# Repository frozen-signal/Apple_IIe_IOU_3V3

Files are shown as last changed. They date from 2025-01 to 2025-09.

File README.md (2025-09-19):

# Description
This repository contains the reference design for a 3.3V version of the Apple IIe's IOU custom IC.</br>
The RTL (VHDL source code) project is located here: [RTL for the Apple IIe's MMU and IOU](https://github.com/frozen-signal/Apple_IIe_MMU_IOU)

## Project status
<br/>

## Acknowledgements

This project was made possible thanks to the support and contributions of a few key individuals.<br/>
Notable thanks go to:
 * **Henry S. Courbis of ReActiveMicro** not only was instrumental in the development of the VHDL code but also was the spark that initiated this project. His generous support and deep technical insight made this project possible.
 * **[Ralle Palaveev](https://github.com/rallepalaveev)** is more than a contributor -- he is the co-creator of the 3.3V adapters. His impressive skills made what seemed impossible look easy: fitting everything into a 40-pin DIP-sized PCB.

And lastly, a special thanks to **Leeland Heins [@SoftwareJanitor](https://github.com/softwarejanitor)**, who thoroughly tested this project. His steady encouragement was a much-appreciated source of motivation during the tougher stretches of development.

## The IOU Adapter
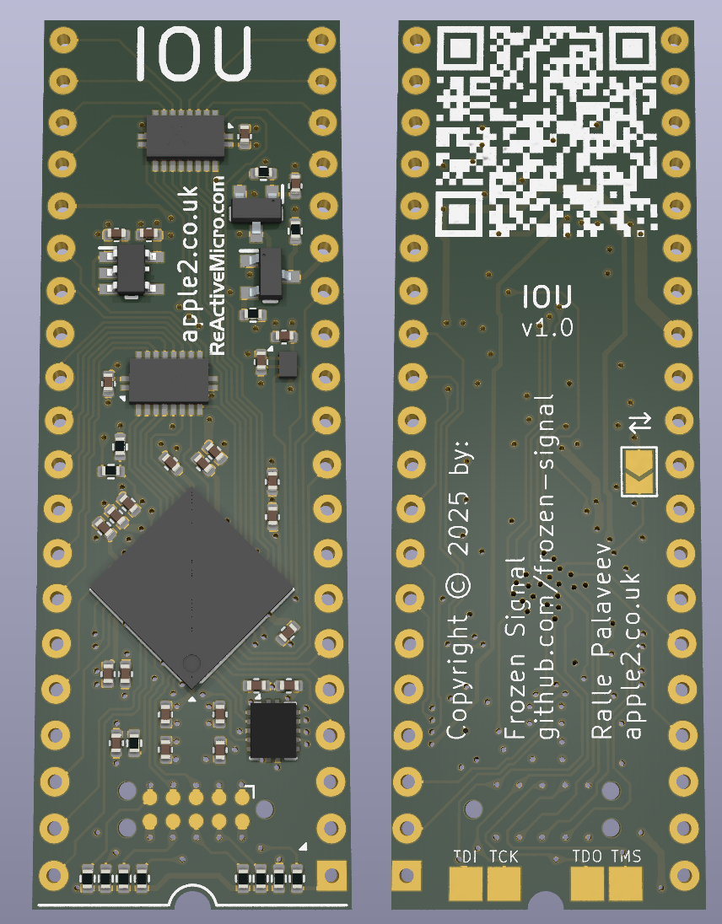
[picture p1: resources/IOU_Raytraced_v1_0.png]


**Buying the IOU Adapter**
<br/>
The two official stores where to buy the IOU adapter are _ReActiveMicro_ and _Ralle Palaveev's store_.<br/>
<br/>
<a href="https://apple2.co.uk/Products">Ralle Palaveev's store</a><br/>
<a href="https://www.reactivemicro.com/">ReActiveMicro</a> (Available soon)<br/>
<br/>

**Building it yourself**
<br/>
Gerbers, production files, and instructions are located in [production](production/)

<br clear="all">

## Tested Hardware

| Category | Hardware Components |
|---|---|
| **Motherboards** | <ul><li>Rev.B motherboard (NTSC)</li><li>ReActiveMicro IIe motherboard (NTSC)</li><li>Pravetz 8E</li><li>Pravetz 8A</li></ul> |
| **CPUs** | <ul><li>Synertek 6502 (unenhanced ROMs)</li><li>Rockwell R6502AP (unenhanced ROMs)</li><li>UMC UM6502 (unenhanced ROMs)</li><li>GTE G65SC02P-2 (enhanced ROMs)</li><li>NCR 65C02 (enhanced ROMs)</li><li>Rockwell R65C02P4 (enhanced ROMs)</li><li>WDC 65C02S (with adapter)</li></ul> |
| **AUX Cards** | <ul><li>RAMWorks III (512M)</li><li>80-Column Expansion Card (820-0067-B)</li><li>80-Column Expansion Card (820-0067-D)</li><li>AE Ramworks ][</li><li>Apple "Slinky" RAM card</li></ul> |
| **ROMs** | <ul><li>Enhanced ROM set (ReActiveMicro)</li><li>Unenhanced ROMs:<ul><li>342-0132-B</li><li>342-0133-A</li><li>342-0134-A</li><li>342-0135-A</li></ul></li></ul> |
| **Disk Interfaces/Drive** | <ul><li>Apple 5.25" Drive Controller Card (655-0101-E)</li><li>Disk ][ Interface Card (650-X104)</li><li>Apple Disk II Drive</li><li>NVRam Drive</li><li>BOMW FloppyEMU</li><li>A2DISK</li><li>Franklin floppy controller</li></ul> |
| **Other** | <ul><li>Mouse Interface Card (670-0030-C)</li><li>Thunderclock Plus</li><li>A2VGA mouse emulation</li><li>Booti</li><li>TJ Boldt's ROM-Drive v4.0</li><li>Grappler+</li><li>A2DVI</li><li>A2Pico</li><li>A2VGA</li><li>Romcard</li><li>Romcard2</li><li>Romcard3</li><li>A2RESET v1,v2</li><li>AE Transwarp</li><li>Titan Accellerator //e</li><li>Ian Kim A2 Turbo</li><li>MS Z80 Softcard clone</li></ul> |

## Other Projects
Other hardware reference designs are located here:
### 3.3V Adapter reference designs
- [3.3V MMU adapter](https://github.com/frozen-signal/Apple_IIe_MMU_3V3)

### 5V Adapter reference designs
- 5V IOU adapter (To be done)
- 5V MMU adapter (To be done)

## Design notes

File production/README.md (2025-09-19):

# Building the IOU Adapter
## DISCLAIMER
This repository is provided "as is". If you choose to fabricate and/or assemble this project yourself, you do so entirely at your own risk. The authors/maintainers provide no warranties (express or implied) and accept no responsibility for any damage, injury, or loss resulting from use or misuse. This design is not certified for safety, EMC, or regulatory compliance; you are solely responsible for verifying suitability, component orientation/polarity, firmware configuration, or any other aspect. By using any files in this repo, you agree to assume all risks.

## Obtaining the PCB
### Required capabilities
Make sure these requirements are within you PCB fab house capabilities:
- Size: 17.46mm x 51.30mm
- 4-Layers
- Smallest via size (hole/dia): 0.3mm / 0.5mm
- Smallest track width: 0.15mm
### BGA solderpads adjustments
Review and/or adjust the BGA's solderpads so that they are within your fab house's mask registration capability or your reflow process if you will be reflowing the components yourself.
Read Lattice's "[PCB Layout Recommendations for BGA Packages (FPGA-TN-02024-5.6)](https://www.latticesemi.com/view_document?document_id=671)" technical note for further details (See section 3 for the 0.5mm ball pitch, csBGA-132).

## Assembly
Soldering the components yourself is not recommended; the FPGA is a 132-ball csBGA (0.5mm pitch) and is beyond the capabilities of most hobbyists. Using the assembly services of your fab house is recommended.
You can use leadframes for the 40 pins of the device, or use 2.54mm pin headers. If you use pin headers, be sure to use a 40-pin socket between them and the Apple IIe's socket; otherwise, the pin headers will damage the Apple IIe's socket.

## Programming
### Requirements
You will need Lattice Diamond to build the code and flash the device.<br/>
Note: You can skip building the JEDEC file by using the one in the [Latest Official Release](https://github.com/frozen-signal/Apple_IIe_IOU_3V3/releases/tag/1.0)

### Build the code
1. Open the project `firmware\IOU.ldf` in Lattice Diamond.
2. In the file `firmware\CUSTOM\IOU.vhdl`, make sure the constant `NTSC_CONSTANT` (line 18) correspond with the version you want:
   | To build this IOU | Use this value |
   | --- | --- |
   | NTSC | `'1'` |
   | PAL | `'0'` |
3. Synthesize and build the JEDEC file

### Flash the MACHXO2
Note: You will need a compatible JTAG programming device to flash the MACHXO2. In doubt, you can use the programmer found here: [JTAG Programmer](https://github.com/frozen-signal/JTAG-Programmer)
1. Connect the programmer and launch the Lattice Diamond Programmer
2. Load the JEDEC file generated earlier
3. Connect the JTAG to the IOU Adapter
4. Program

## Finished
The adapter is ready to be used. Make sure to insert the adapter with the correct orientation in the Apple IIe.

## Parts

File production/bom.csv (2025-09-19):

Designator | Footprint | Quantity | Value | LCSC Part #
 | 72190c3a-44d7-4d1f-8c19-bd071d7af191 | 1
C1, C2, C25 | 0402 | 3 | 1uF
C10, C11, C13, C14, C16, C17, C18, C20, C21, C23, C24, C3, C4, C5, C6, C8 | 0402 | 16 | 100nF
C12, C15, C19, C22, C7, C9 | 0402 | 6 | 10uF
Q1, Q2 | SOT95P240X120-3N | 2 | BSS138 | C7420339
R1, R10, R11, R14, R3, R5, R6, R7, R8, R9 | 0402 | 10 | 4.7K
R12, R13, R2 | 0402 | 3 | 5.1K
R4 | 0402 | 1 | 1K
U1 | SOT95P280X145-5N | 1 | TLV75733PDBVR
U2 | BGA132C50P14X14_800X800X135 | 1 | LCMXO2-256HC-4MG132C
U3 | TXU0101DRYR | 1 | TXU0101DRYR
U4, U6 | 74LVC245ABQ115 | 2 | 74LVC245ABQ,115
U7 | TXU0204BQAR | 1 | TXU0204BQAR

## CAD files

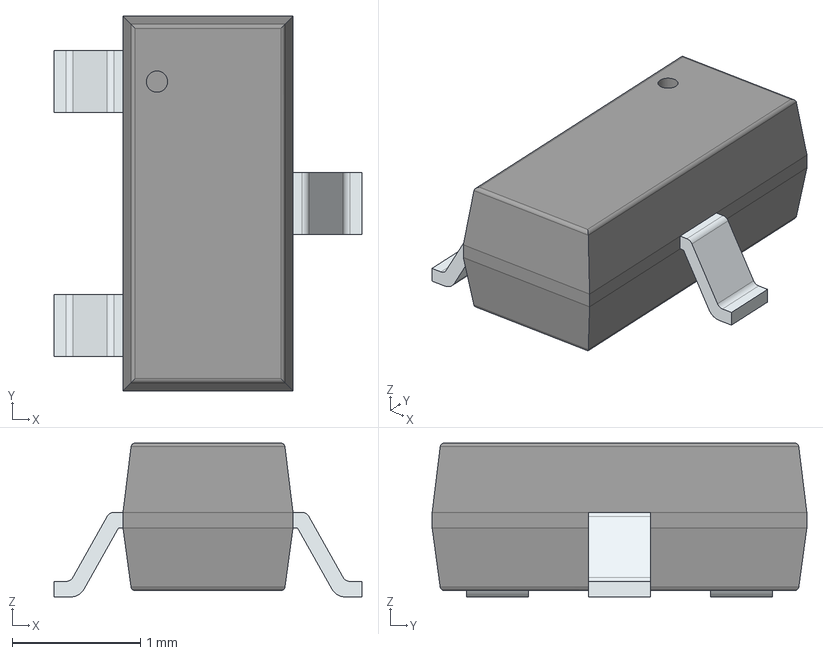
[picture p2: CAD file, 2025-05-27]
3D_Models/BSS138.step
2.40 x 2.92 x 1.20 mm
PinsArrayL
FilletPinR

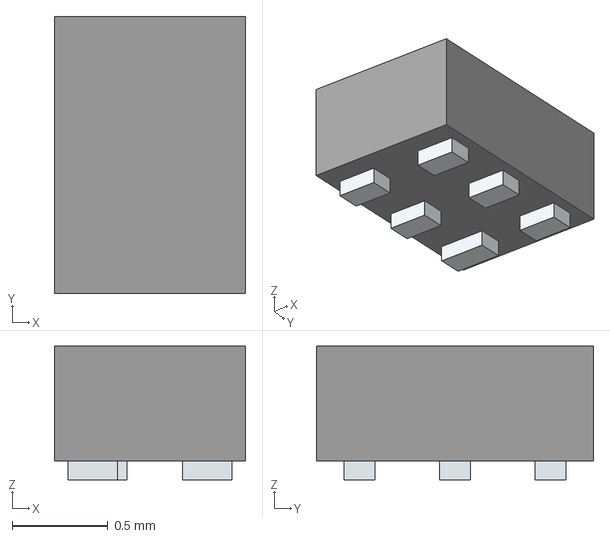
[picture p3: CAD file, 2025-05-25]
3D_Models/TXU0101DRYR.step
1.00 x 1.45 x 0.7 mm
Pins

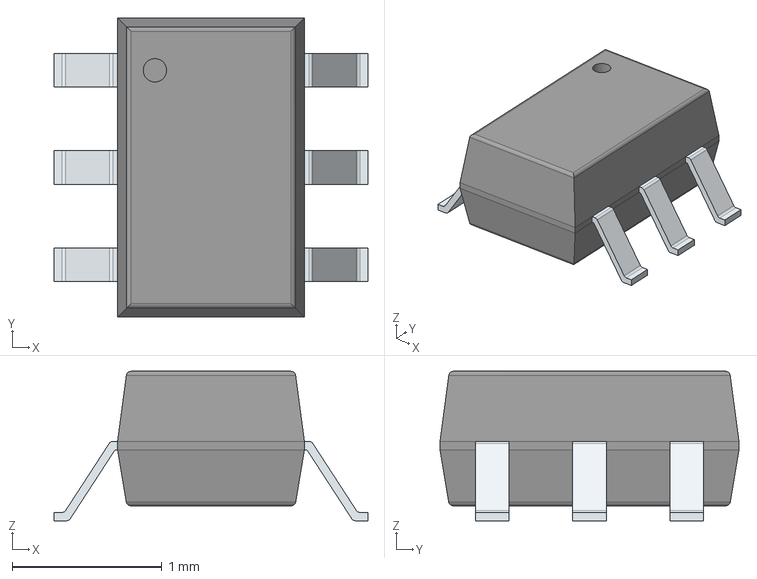
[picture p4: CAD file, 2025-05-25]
3D_Models/BSD235NH6327XTSA1.step
2.10 x 2.00 x 1.00 mm
PinsArrayLR

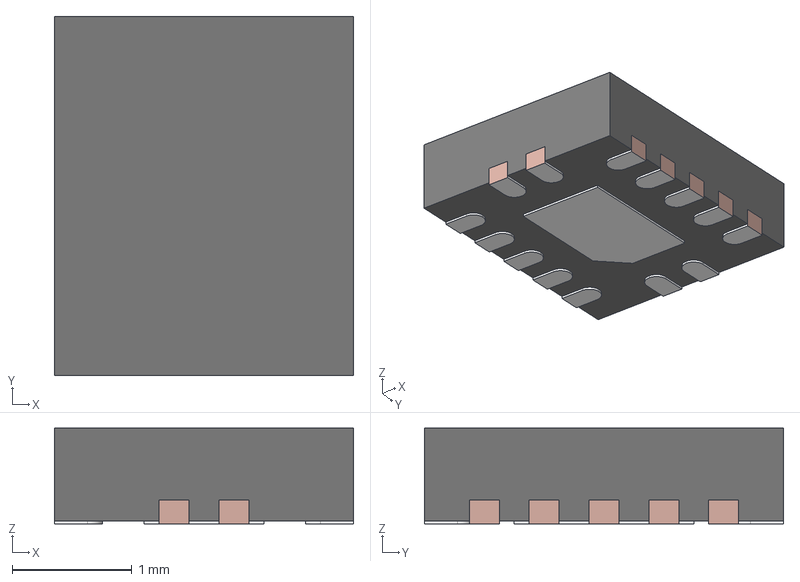
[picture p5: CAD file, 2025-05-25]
3D_Models/TXU0204BQAR.step
2.50 x 3.00 x 0.8 mm
FRAME

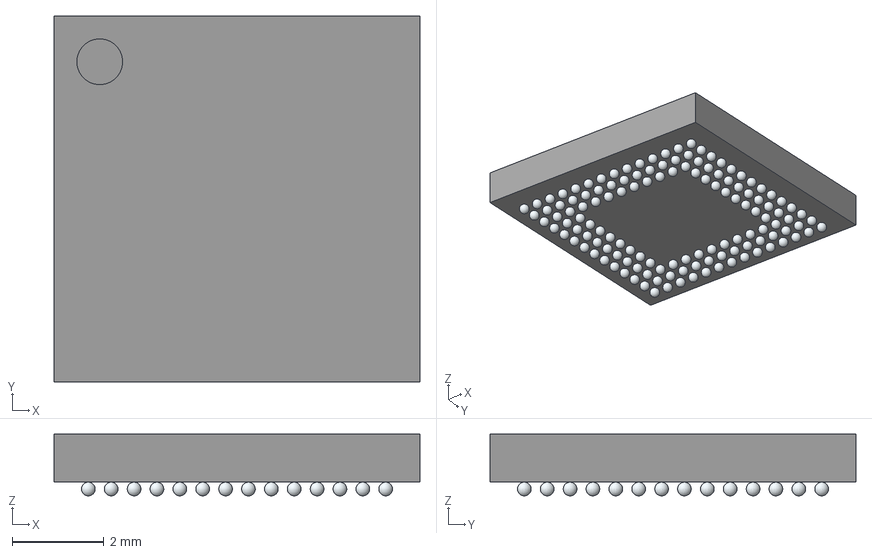
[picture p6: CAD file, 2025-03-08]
3D_Models/LCMXO2-256HC-4MG132C.step
8.00 x 8.00 x 1.35 mm
A1
A2
A3
A4
A5
A6
A7
A8
A9
A10
A11
A12
A13
A14
B1
B2
B3
B4
B5
B6
B7
B8
B9
B10
B11
B12
B13
B14
C1
C2
C3
C4
C5
C6
C7
C8
C9
C10
C11
C12
C13
C14
D1
D2
D3
D12
D13
D14
E1
E2
E3
E12
E13
E14
F1
F2
F3
F12
F13
F14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

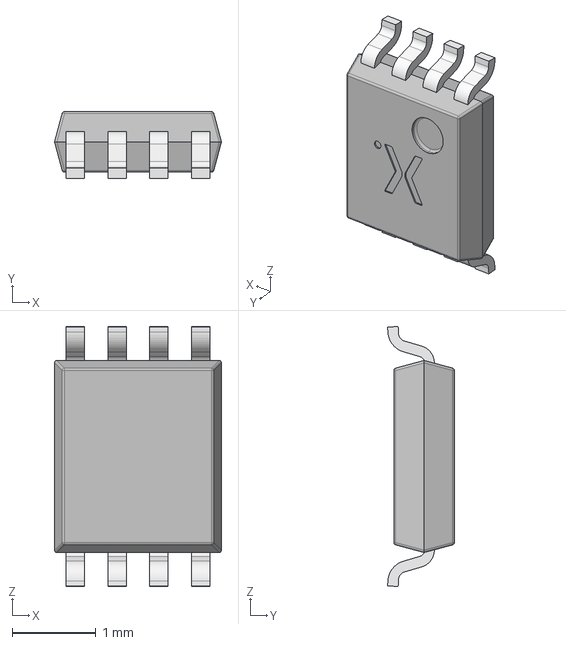
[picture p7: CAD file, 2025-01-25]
3D_Models/LSF0102DCH.step
2.00 x 0.8 x 3.11 mm
SOT765 Mold body
SOT765 Lead x 8

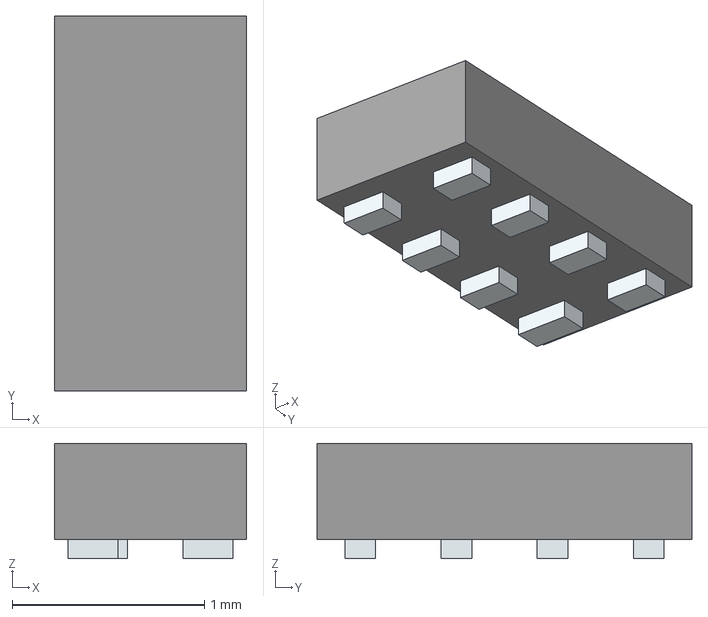
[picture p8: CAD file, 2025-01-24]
3D_Models/TXU0102QDTTR.step
1.00 x 1.95 x 0.6 mm
Pins

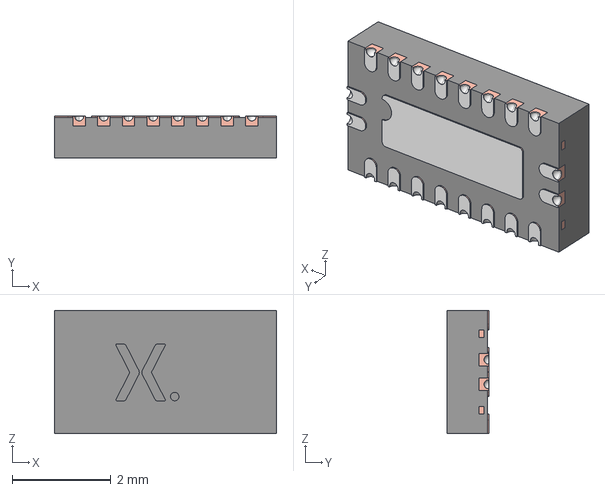
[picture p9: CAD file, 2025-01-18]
3D_Models/74LVC245ABQ,115.step
4.50 x 0.85 x 2.50 mm
SOT764-1 LF
SOT764-1 Mold Body

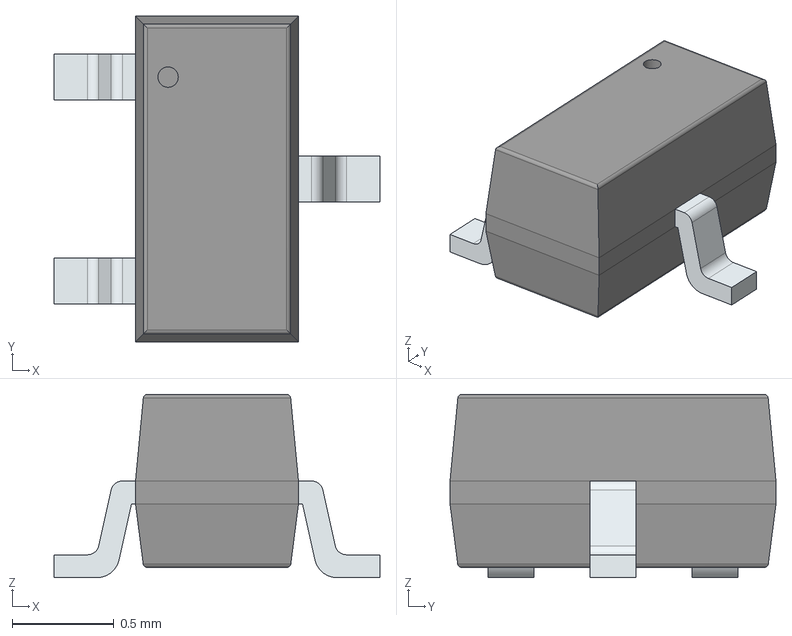
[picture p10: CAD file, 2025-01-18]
3D_Models/DMG1012TQ-7.step
1.60 x 1.60 x 0.9 mm
PinsArrayL
FilletPinR

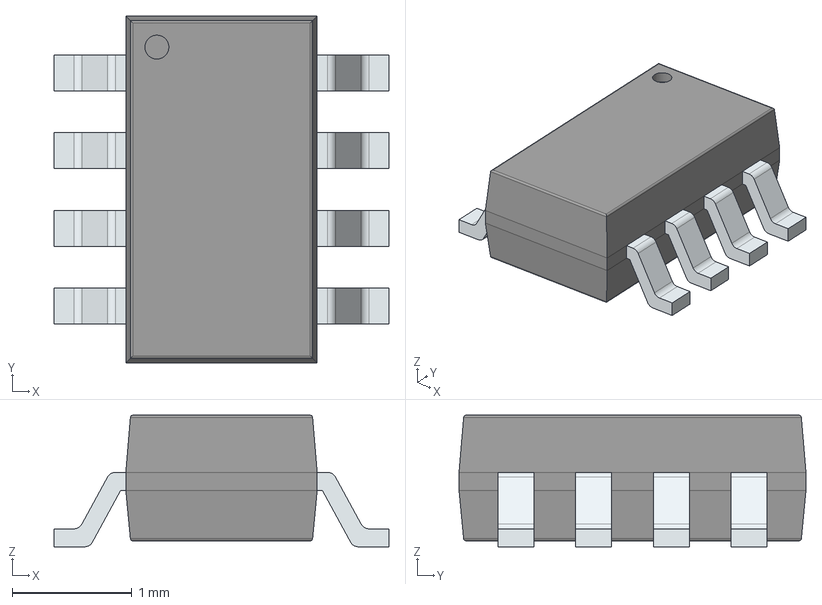
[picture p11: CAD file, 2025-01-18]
3D_Models/LSF0102DDFR.step
2.80 x 2.90 x 1.10 mm
PinsArrayLR

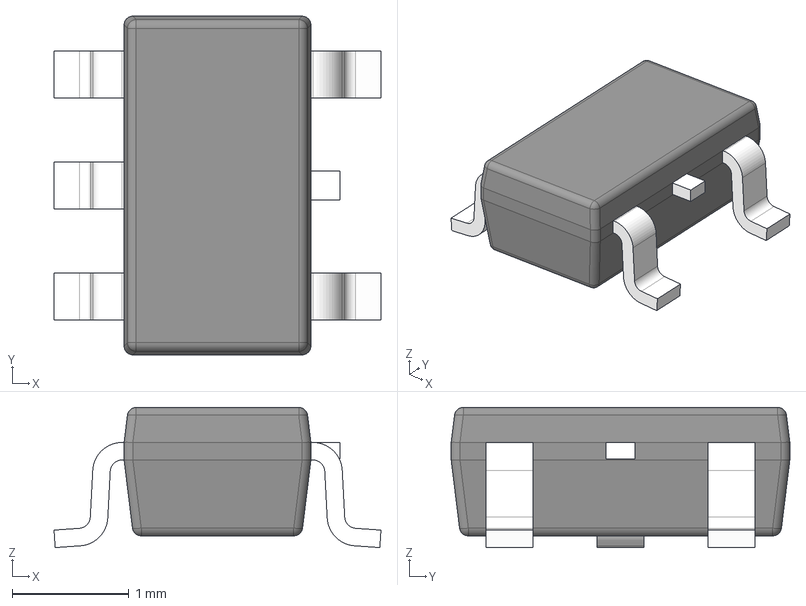
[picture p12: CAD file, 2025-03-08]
3D_Models/TLV75733PDBVR.step
2.80 x 2.90 x 1.20 mm
BODY-SOT
LEAD-SOT x 5
LEAD-DUMMY

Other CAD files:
3D_Models/LSF0108BQ-Q100X.step

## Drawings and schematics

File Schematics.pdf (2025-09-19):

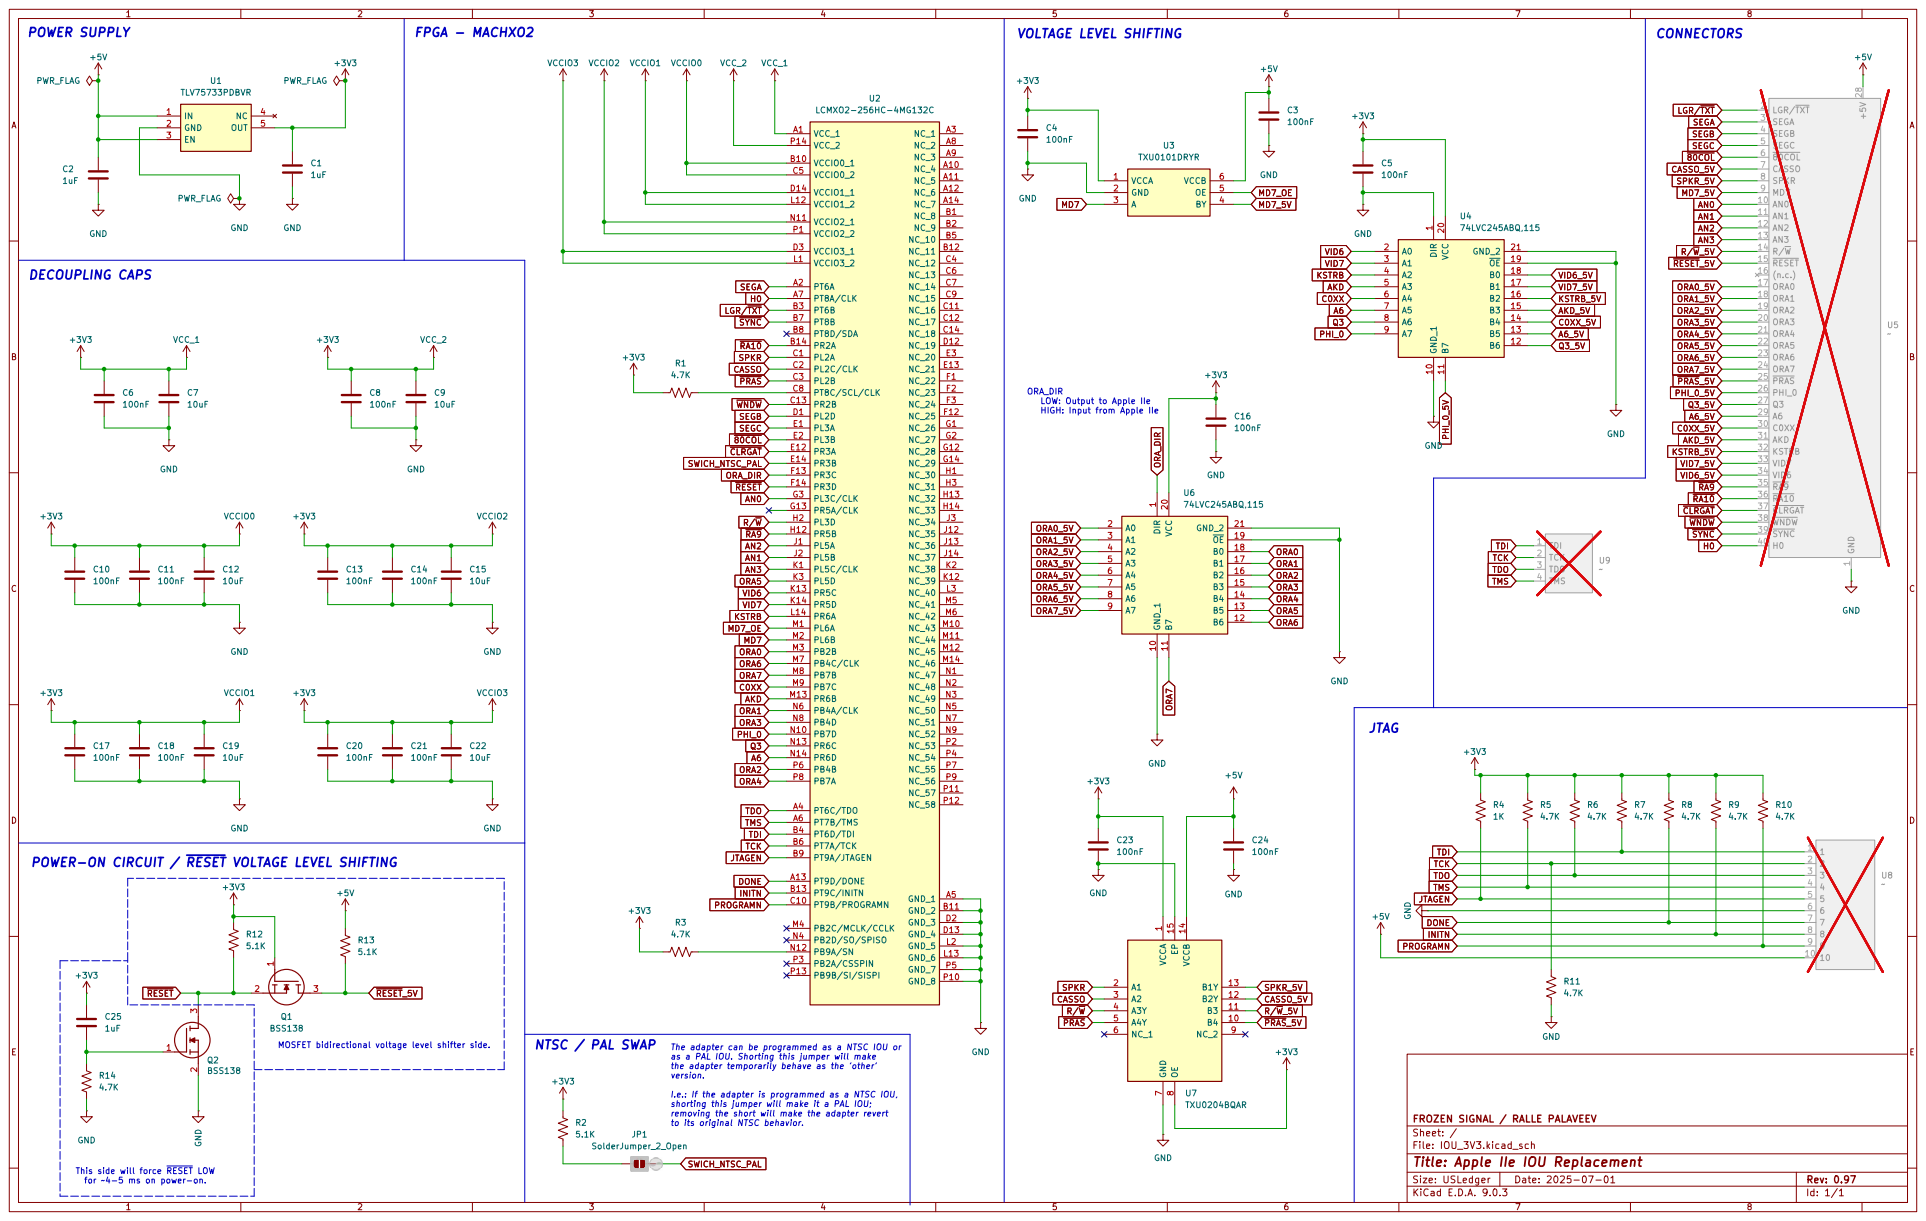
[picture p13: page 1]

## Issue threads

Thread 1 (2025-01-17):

Impossible to write to Flash Memory

frozen-signal, 2025-01-17:
When powered, the FPGA attempts to read its configuration from the memory and generate a clock signal on its SPI pins, and never timeout. This makes writing to memory impossible.

We will not use CRESETB, but instead inject power through the unused pins of the TC2030 connector while making sure the iCE40 remains unpowered while writing to memory. This will make programming multiple adapters easier.

frozen-signal, 2025-01-24:
Fixed by https://github.com/frozen-signal/Apple_IIe_IOU_3V3/commit/baebc97368f1fc1a2cfa16c09c4146185dd94b4d
Will need to be tested though.

frozen-signal, 2025-02-15:
Confirmed as working in TAG [0.95-prototype](https://github.com/frozen-signal/Apple_IIe_IOU_3V3/releases/tag/0.95-prototype)

Closed 2025-02-15.

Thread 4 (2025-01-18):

Signals CASSO and SPKR are 3.3V

frozen-signal, 2025-01-18:
These are wired directly to the 3.3V FPGA and on the board SPKR is wired to a5V pull-up. At least SPKR need to be level-shifted to 3.3V, but also doing it for CASSO won't be more trouble.

frozen-signal, 2025-01-24:
Fixed by https://github.com/frozen-signal/Apple_IIe_IOU_3V3/commit/2574525c2a7e6f6c2638d5cf1d53a2fd1ab9ae75

Closed 2025-01-24.

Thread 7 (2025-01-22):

Change the 1.2V LDO

frozen-signal, 2025-01-22:

frozen-signal, 2025-01-25:
Fixed in https://github.com/frozen-signal/Apple_IIe_IOU_3V3/commit/9f2505e8701c3f4659f0df3f922fe0535eec22ce

Closed 2025-01-25.

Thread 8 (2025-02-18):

LED pins cannot be used as regular GPIOs

frozen-signal, 2025-02-18:
The datasheets mention that LED pins in the iCE40 can be configured as GPIOs. The documentation on these is sparse and superficial. This is what's specified in [Technical Note TN1288](https://www.latticesemi.com/-/media/LatticeSemi/Documents/ApplicationNotes/IK/ICE40LEDDriverUsageGuide.ashx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):

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

So we must change the design to use them as inputs instead or add a pull-up resistor to them.

frozen-signal, 2025-02-20:
Adding pull-up resistors to the low side of the LSF0108 is not a good idea.
Connections to the LED pins has been swapped to have input-only signals (except /RESET which need an open-drain)

Fixed by https://github.com/frozen-signal/Apple_IIe_IOU_3V3/commit/80d5e11016aa82debadeb1b0287f5c0de69735a6

Closed 2025-02-20.

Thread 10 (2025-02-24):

Switch the FPGA to the MACHXO2

frozen-signal, 2025-02-24:
Experiments while developping the 3.3V MMU adapter shows that the iCE40 cannot be used. The FPGA has a "budget" of ~35 ms to configure itself, and a iCE40UP5K takes ~68 ms. Even using a faster configuration speed or a smaller FPGA still can't make it below the limit. So, using a iCE40 is not viable (unless using NVCM).

Switch to a MACHXO2 132-ball csBGA

frozen-signal, 2025-03-08:
Probably fixed by https://github.com/frozen-signal/Apple_IIe_IOU_3V3/commit/67aee5996a8b19e9f4f3283d87419e061810057d

Closed 2025-05-25.

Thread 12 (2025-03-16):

Wiring of the LSF010X's decoupling capacitors are incorrect

frozen-signal, 2025-03-16:
The decoupling capacitor should be directly connected to REFB and 'behind' the 200K resistor.
Current and incorrect wiring in the adapter:

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

Correct wiring from the datasheet:

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

frozen-signal, 2025-05-25:
We don't use LSF anymore

Closed 2025-05-25.

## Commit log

2025-01-18 Design files initial commit
    [74LVC245ABQ,115.step, DMG1012TQ-7.step, ICE5LP1K-SG48ITR.step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]
2025-01-18 Added a FIXME
    [IOU_3V3.kicad_sch]
2025-01-18 Changed the connector to TC2050
    [IOU_3V3.kicad_pcb, iou.kicad_sch]
2025-01-20 Updated some labels
    [IOU_3V3.kicad_pcb]
2025-01-20 Fixed the page-within-a-page problem in the schematics (#5)
    Fixed the page-within-a-page problem in the schematics
    [IOU_3V3.kicad_pcb, IOU_3V3.kicad_sch, iou.kicad_sch]
2025-01-22 Fix page within page (#6)
    [IOU_3V3.kicad_pcb, IOU_3V3.kicad_sch]
2025-01-24 Added lvl-shift for CASSO & SPKR
    [IOU_3V3.kicad_pcb, IOU_3V3.kicad_sch, REMOVE_DMP2104LP-7.step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]
2025-01-24 Changed the FPGA to ICE40UP5K-SG48I
    [IOU_3V3.kicad_pcb, IOU_3V3.kicad_sch]
2025-01-25 Changed the 1.2V LDO
    [IOU_3V3.kicad_pcb, IOU_3V3.kicad_sch]
2025-01-25 Changed the LSF0102 to a LSF0102DCH
    [IOU_3V3.kicad_pcb, IOU_3V3.kicad_sch, LSF0102DCH.step]
2025-01-25 Hopefully the last changes before hopefully the last prototype version
    [IOU_3V3.kicad_pcb, IOU_3V3.kicad_sch]
2025-01-27 Added larger programming pads
    [IOU_3V3.kicad_pcb, IOU_3V3.kicad_sch]
2025-02-18 Changed version to v0.96
    [IOU_3V3.kicad_pcb, IOU_3V3.kicad_sch]
2025-02-20 Rerouted input-only signals to LED pins (#9)
    [IOU_3V3.kicad_pcb, IOU_3V3.kicad_sch]
2025-03-08 Changed the FPGA to a MACHXO2 (#11)
    [ICE5LP1K-SG48ITR.step, IOU_3V3.kicad_pcb, IOU_3V3.kicad_sch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]
2025-04-03 Fixed incorrect LSF0108 connection
    [IOU_3V3.kicad_pcb, IOU_3V3.kicad_sch]
2025-05-25 Finalized Kicad and firmware (#13)
    [BSD235NH6327XTSA1.step, IOU_3V3-o.kicad_sch, IOU_3V3.kicad_pcb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]
2025-05-26 Added DNP to connectors & adjusted resistor values for JLCPCB
    [IOU_3V3.kicad_pcb, IOU_3V3.kicad_sch]
2025-05-27 Changed the dual-MOSFET for 2x BSS138
    [BSS138.step, IOU_3V3.kicad_pcb, IOU_3V3.kicad_sch]
2025-05-28 Final changes before release candidate
    [IOU_3V3.kicad_pcb, IOU_3V3.kicad_sch]
2025-05-28 Small trace width adj., schematics page size to us-ledger
    [IOU_3V3.kicad_pcb, IOU_3V3.kicad_sch]
2025-05-28 Release Candidate
    [IOU_3V3.kicad_pcb]
2025-07-02 Final changes before v1.0
    [IOU_3V3.kicad_pcb, IOU_3V3.kicad_sch]
2025-07-15 Updated README and added link to ReActiveMicro
    [IOU_3V3.kicad_pcb]
2025-09-19 Added documentation, production files, and schematics. (No functional changes) (#14)
    [IOU_3V3.kicad_pcb, IOU_3V3.kicad_sch, bom.csv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]
